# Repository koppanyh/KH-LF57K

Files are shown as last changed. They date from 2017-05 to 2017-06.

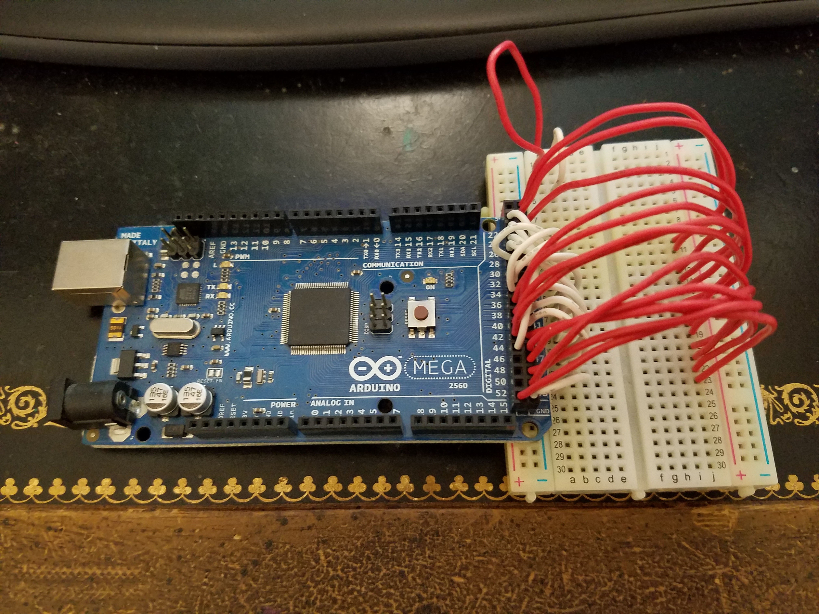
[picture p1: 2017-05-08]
hardware/programmer_real.jpg

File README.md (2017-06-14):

# KH-LF57K
Code and design files for a custom Z80 computer with Forth operating system.

The KH-LF75K computer is a Z80 based single-board computer that was designed, built, and programmed by Koppany Horvath as a project for the University of La Verne's 2nd Mini Makers fair. The first version (0.9.4) of the code was over 1300 lines of assembly and written in less than a week; no small feat when you consider that I never wrote a line of Z80 assembly before.

This is a collection of the software files for the operating system itself as well as any firmware for the Arduino microcontrollers used. Schematics and documentation of the hardware will also be stored here.

All of this content here is free to use for whatever you want. It is under the MIT License but I also require that you mention my name or GitHub account if you use any of my resources for anything.

Read the "/UsersManual.pdf" file for more information on the computer.

The "/arduino/eepromprog" folder has the sketch for an Arduino Mega 2560 based EEPROM programmer and the schematic to hook it up.
The "/arduino/z80controller" folder contains the sketch for the Arduino Nano based serial communication module used on the KH-LF57K computer.

The "/forth" folder contains the source code for the Forth operating system. This is a custom Forth implementation that is not ANSI compliant and works a little differently than most traditional Forth implementations.
The "/forth/forth.cpp" file is the C++ file that contains a Forth interpreter/compiler prototype that was used for porting the interpreter to Z80 assembly.
The "/forth/z80os.asm" file is the assembly file that contains the ported version of the Forth interpreter from the C++ file; it is specifically written for the KH-LF57K computer but should be easy to port to another Z80 based system by modifying the addresses and input/output subroutines; it also contains a 2 byte header that holds the size of the code to be uploaded to the Arduino for EEPROM programming.
The "/forth/buildscript.sh" file is a script that re-compiles the assembly file every time there is a change to it.

The "/hardware/computer_layout.{png,svg}" files are rought schematics of the laout of the actuall KH-LF57K board. The address (yellow) and data (green) lines aren't shown, but to complete the circuit, just connect all the data lines for all the chips to the right ones on the Z80, same for the address lines. The Arduino Nano uses pins D2-D9 as the data lines for D0-D7.
The "/hardware/computer_layout.fzz" file is the Fritzing file for the computer_layout files.
The "/hardware/eeprom_programmer_schem.{png,svg}" files are a rough schematic of how to hook up the Arduino Mega 2560 to the EEPROM chip.
Schematics use red for positive 5 volts, black for ground, white for signal lines, yellow for address lines, and green for data lines.
The capacitor on the computer is rated at 0.47 uf.

The "/computer_real.jpg" and "/programmer_real.jpg" files are pictures of the actual computer and the actual programmer circuit. You'll might notice a few differences, like the chips being wider or the power supply being different, but those small details won't affect the computer.

The "/z80os-0.9.4.bin" file is the compiled version of the "/forth/z80os.asm" file; the first 2 bytes are the size of the program, the rest is the program starting from address $0000.
This file was compiled with version 1.8 of the z80asm assembler program.

**To Do**
* look into potential bug that looks through whole memory for command
* write all built-in words in assembly for speed and finish words in assembly
* fix all comparisons to use the cp opcode instead of sbc
* add over/underflow errors to return and loop stacks
* fix the stack functions to use the hardware stack
* fix backspacing into other memory

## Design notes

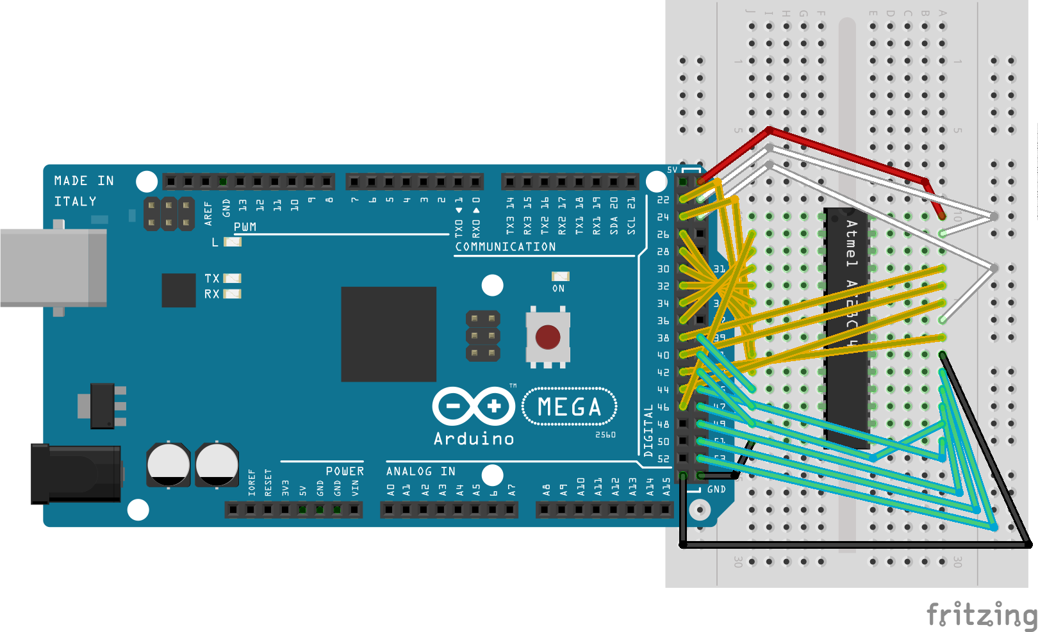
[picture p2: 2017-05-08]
hardware/eeprom_programmer_schem.png

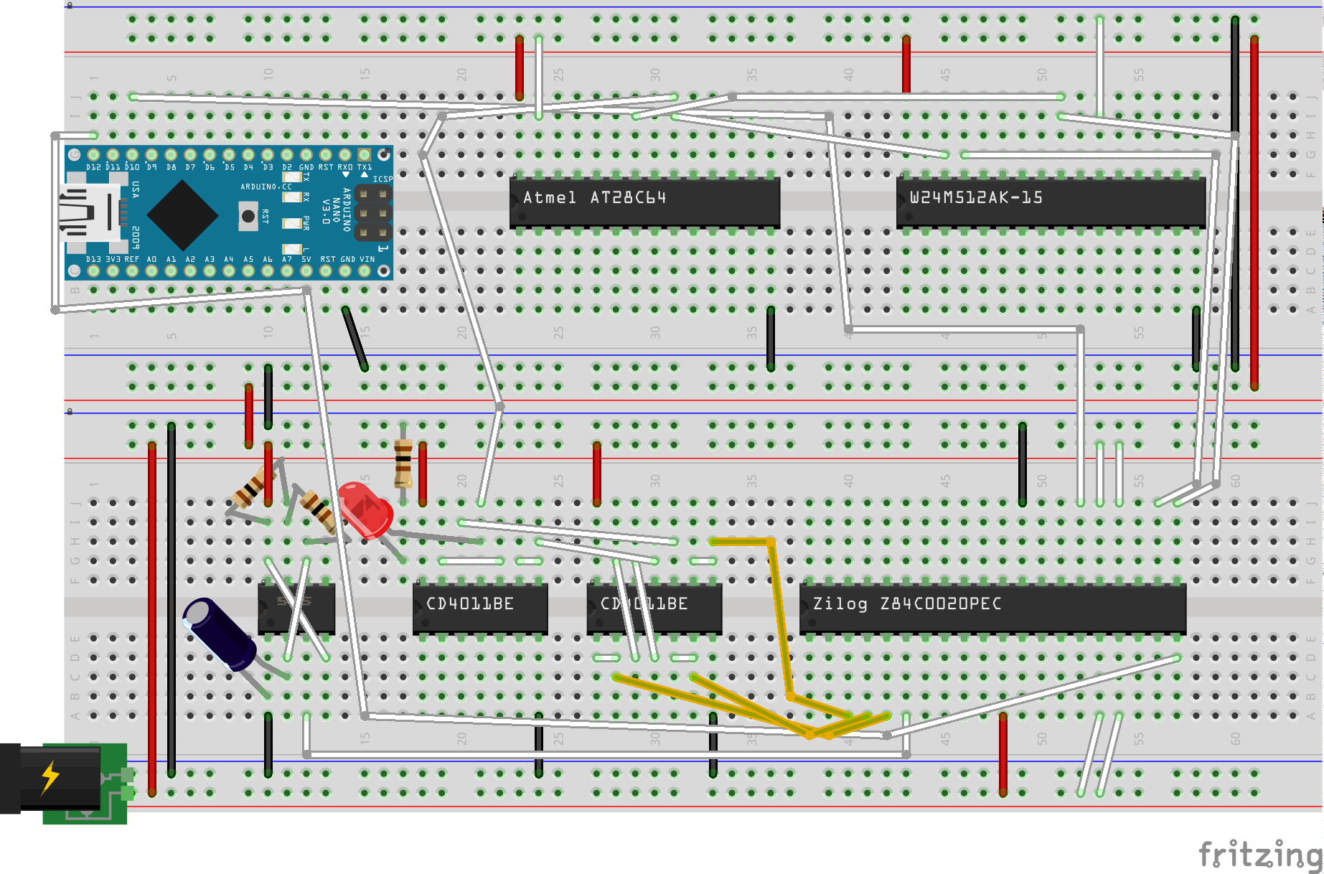
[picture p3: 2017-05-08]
hardware/computer_layout.png

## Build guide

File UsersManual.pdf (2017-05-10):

# KH-LF57K

© 2017 KH-Labs

Developer’s User Manual

“The best 1980s computer made from 1970s and 1990s technology!” -Koppany Horvath

Rev 1.0 - 2017 / 05 / 09

## Contents

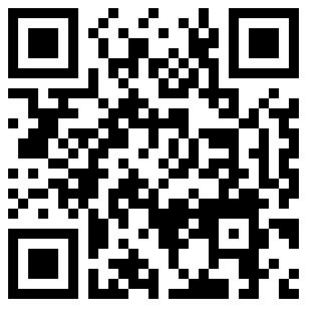
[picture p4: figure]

Additional Resources: https://github.com/koppanyh/KH-LF57K

Rev 1.0 1

## General Description

The KH-LF57K computer is a microcomputer designed by the KH-Labs development team with the goal of being built from the bare minimum parts required to run a Forth operating system on a Zilog Z80 processor with memory, a ROM, and serial communications capabilities. The name KH-LF57K stands for KH-Labs Forth OS 57 KB of RAM Microcomputer.
This computer was designed and built for the initial purpose of entering the University of La Verne’s second annual Mini Maker Fair. It took a week to write and debug the operating system. The Z80 assembly language was never used by the development team before. Future plans for the computer involve research into 1980s software development along with work on optimizing the Forth operating system. Work on upgrading the hardware and speeding up the computer is also planned. If possible, working on giving the computer the look and feel of an authentic 1980s computer, particularly with the style of CBM computers, will also be attempted.

## Hardware Specs

- 8 bit Zilog Z80 processor
- 10.34 KHz clock speed
- 57 KB of RAM
- 8 KB of ROM memory
- 115200 baud serial module
- CMOS memory switching logic

## Addressing/Serial

The addressing capabilities of the KH-L57K computer are split between the ROM, RAM, and serial module.
The ROM can be addressed between addresses 0x0000 and 0x1FFF.
The RAM can be addressed between 0x2000 and 0xFFFF.
The serial module can be addressed using the IO request line. The first IO request will have to be sending data to the serial module as the serial module will be in a listening mode, then the second IO request will receive data from the serial module as the serial module will be waiting to transmit. The serial module then switches to receiving mode and waits for another byte from the processor. The serial module is capable of asynchronously transmitting and receiving between the processor and a serial terminal at 115200 baud. The serial module can buffer at most 64 bytes of data from a serial terminal waiting to be read by the processor. The serial module does not buffer data from the processor but instantly transmits each byte to the serial terminal.

## Block Diagram

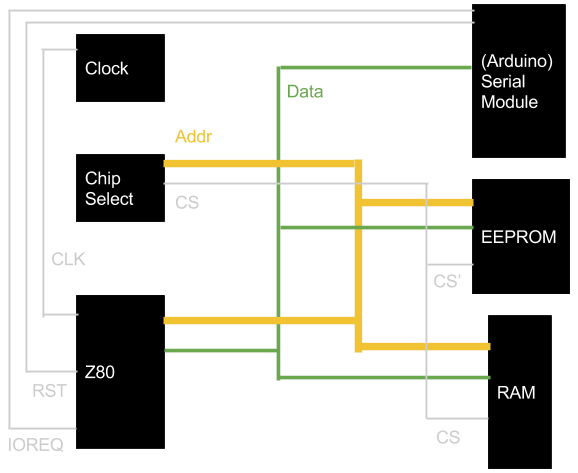
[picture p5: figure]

## Parts List

- 1x MB102 Breadboard Power Supply
- 1x Zilog Z84C0020PEC CMOS Z80 CPU
- 1x AT28C64-15PC 8KX8 EEPROM
- 1x W24M512AK-15 64KX8 SRAM
- 1x Arduino Nano Microcontroller
- 1x 0.47 µf Electrolytic Capacitor
- 2x CD4011 Quad NAND Gates
- 1x Red Difuse LED
- 1x LM555 Timer IC
- 3x 100 Ω Resistors

## Schematics

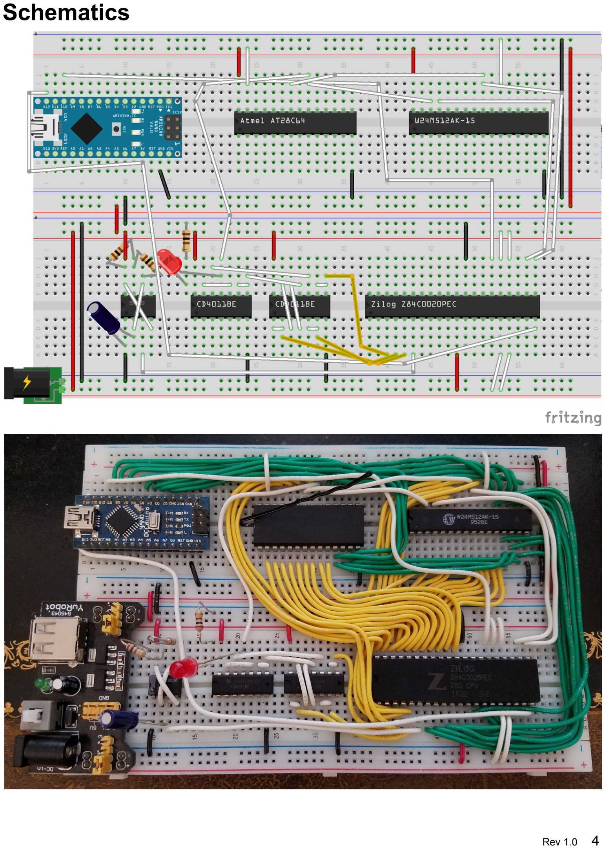
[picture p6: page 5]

The first figure is a rough representation of the layout of the computer without address or data lines. To complete the schematic, the data lines simply need to be connected to between the corresponding data pins on the processor, ROM, RAM, and serial module. The serial module uses pins D2-D9 as data pins 0-7 correspondingly. The address lines need to be connected between the address pins on the processor, ROM, RAM, just like the data lines. The serial module does not require address lines to operate.
The second figure shows a built KH-LF57K computer. The figure demonstrates the connections of the address (yellow) and data (green) lines between the processor (bottom right), RAM (top right), ROM (top middle), and serial module (top left).
In the first figure, there are 3 address lines going from the processor to the CMOS memory switching logic chips (bottom middle). These are 2 2-input quad NAND chips wired to work as a 3-input OR gate. Addressing the RAM will set the top 3 address bits high and trigger a high response on the OR gate which will select the RAM chip for reading and writing. Addressing the ROM under that will deactivate the OR gate and select the ROM chip.
A 555 timer chip is used to provide the clock signal at about 10.34 KHz. The 555 timer is configured as an astable oscillator. Unfortunately this particular clock circuit is not the most accurate and is subject to problems such as thermal drift and slightly different frequencies per unit due to the precisions and tolerances of the components being slightly different. The processor can run at 20 MHz but no more than 1 MHz is recommended as it may be too fast to interface with the serial module.

## Forth OS

The Forth language was chosen for the operating system of the KH-LF57K computer because of its ease of implementation and the small resources that are required to run it. The Forth language can generally fit in less space than BASIC, is natively extensible through the use of the built-in compilation capabilities, and has been around since 1970.
Forth is a stack-based language that uses reverse Polish notation (or post-order notation) and is also its own development environment. Words, functions in Forth, are created using the concept of concatenative programming. A more detailed explanation of the Forth language can be found on Wikipedia.com at the following address: https://en.wikipedia.org/wiki/Forth_(programming_language)
The Forth version in use at the time of this revision is 0.9.4; keep in mind that this is a custom implementation of Forth and the version number is not related to any other Forth implementations or standards.
An example of adding 5 and 4 and printing it out in Forth can be seen below:
5 4 + .
This code pushes 5 and 4 onto the top of the stack. Then it adds the top 2 items of the stack together with the plus operator. Then it prints out the result at the top of the stack with the period operator.

An example of defining a Forth word that prints the double of a number at the top of the stack can be seen below:
: double 2 * . ;
This code starts the compilation sequence with the colon operator and creates the header for the word double. It then defines the word based on the operators following the name. When called, this code will push 2 to the top of the stack. It then will multiply the 2 with the second number on the stack using the multiplication operator and will leave the result at the top of the stack. Then it will use the period operator to print out the result at the top of the stack.
The semicolon operator ends the compilation sequence and the word double | can be seen as
the first word when the words | word is called.
To use the new double | word, simply enter in a number and call double | as seem
below:
| 7 double
This code will push 7 to the top of the stack and then call the word double | to multiply
the number by 2 and print the result.
Here is a table of all the Forth words that have been implemented in version 0.9.4 of the Forth OS. For the flags, M means it is machine code, I means it is an immediate word, C means it it compiled. Lack of M means it is written in Forth, lack of I means it compiles normally, lack of C means that it can be used out of compilation.
Name | Flags | Stack Action | Description
LIT | MC | ( -- n1 ) | get next number from program and push to stack
, | M | ( n1 -- ) | writes n1 into the memory at WEND and updates WEND position
+ | M | ( n1 n2 -- n3 ) | add n2 to n1
- | M | ( n1 n2 -- n3 ) | subtract n2 from n1
* | M | ( n1 n2 -- n3 ) | multiply n2 to n1
/mod | M | ( n1 n2 -- n3 n4 ) | divide and mod n2 from n1
emit | M | ( n1 -- ) | output the character of the ascii value of n1
, | M | ( n1 -- ) | display n1 followed by a space
CREATE | M | ( n1 -- ) | create the header for a word/constant/variable from string address n1
c! | M | ( n1 n2 -- ) | save the low 8 bits of n1 to the address n2
c@ | M | ( n1 n2 -- ) | get the byte at the address n1
! | M | ( n1 n2 -- ) | save n1 to the address n2

@ | M | ( n1 -- n2 ) | get the value at the address n1
STATE | | ( -- n1 ) | leave the address of the state variable in the stack, 0 is interpret, -1 is compile
LATEST | | ( -- n1 ) | leave the address of the latest word variable in the stack
WEND | | ( -- n1 ) | leave the address of the end of words variable in the stack
BKEY | MC | ( -- n1 ) | gets next char from input buffer and leaves in stack
BWORD | MC | ( -- n1 ) | gets next word in input buffer and leaves address in stack
: | I | ( -- ) | start compiling sequence, create and state to -1
; | IC | ( -- ) | add 0xffff to the end of program and make state 0
key | M | ( -- n1 ) | get the ascii value of the first key pressed
word | M | ( -- n1 ) | gets a string from input and leaves the address of the string
number | M | ( -- n1 ) | gets a number from input
words | M | ( -- ) | display all the words in the forth dictionary
swap | M | ( n1 n2 -- n2 n1 ) | switch the top 2 elements on the stack
dup | M | ( n1 -- n1 n1 ) | duplicates top of stack
drop | M | ( n1 -- ) | pop n1 from stack
= | M | ( n1 n2 -- n3 ) | true if n1 equals n2, else false
<> | M | ( n1 n2 -- n3 ) | true if n1 not equals n2, else false
< | M | ( n1 n2 -- n3 ) | true if n1 less than n2, else false
> | M | ( n1 n2 -- n3 ) | true if n1 greater than n2, else false
<= | M | ( n1 n2 -- n3 ) | true if n1 less than equal n2, else false
>= | M | ( n1 n2 -- n3 ) | true if n1 greater than equal n2, else false
and | M | ( n1 n2 -- n3 ) | logic and n1 & n2
or | M | ( n1 n2 -- n3 ) | logic or n1 & n2

xor | M | ( n1 n2 -- n3 ) | logic xor n1 & n2orr
.s | M | ( -- ) | display all the numbers in the stack without popping the stack
reboot | M | ( -- ) | restarts the computer
>r | M | ( n1 -- ) | push n1 to the return stack
r> | M | ( -- n1 ) | pop n1 from the return stack
r@ | M | ( -- n1 ) | copy the top value from the return stack
>l | M | ( n1 -- ) | push n1 to the loop stack
l> | M | ( -- n1 ) | pop n1 from the loop stack
type | M | ( n1 -- ) | string is displayed starting from the address n1
FIND | M | ( -- n1 ) | find the address n1 of a word with name in wordbuff
WBUFF | | ( -- n1 ) | leaves the address of the start of the word buffer in the stack
EXEC | M | ( n1 -- ) | executes the word with address n1
BRANCH | MC | ( -- ) | replace the top of return stack with next number in program
0BRANCH | MC | ( -- ) | replace the top of return stack with next number in program if top of stack is 0
VERSION | | ( -- n1 ) | leave the forth version * 100 on the stack
constant | I | ( n1 -- ) | create a word that leaves the value n1 in the stack
variable | I | ( -- ) | create a word that leaves the address for a variable in the stack

## Useful Forth Words

As can be seen from the table above, there are many Forth words that have been defined and added into version 0.9.4 of the operating system, but not all of the most common words have been added. This was due to time constraints and accepting the trade-off of not having the words but having the capability to produce them on the spot.

The following code is the human definition (prefixed by a comma) of the words followed by their Forth definition.
; / | ( n1 n2 -- n3 ) divide n1 by n2, leave result n3
: / /mod drop ;
; mod | ( n1 n2 -- n3 ) get n1 modulus n2, leave result n3
: mod /mod swap drop ;

; negate ( n1 -- n2 ) leaves 2's complement of n1 in stack
: negate 0 swap - ;

; over ( n1 n2 -- n1 n2 n1 ) duplicates second number in stack : over >l dup l> swap ;

; rot | ( n1 n2 n3 -- n2 n3 n1 ) rotates third number to top
: rot >l swap l> swap ;

; -rot ( n1 n2 n3 -- n3 n1 n2 ) rotates top to third place
: -rot swap >l swap l> ;

; cells ( n1 -- n2 ) multiplies n1 with size of number cell (2) : cells 2 * ;

; cr | ( -- ) prints a carriage return and newline
: cr 13 emit 10 emit ;

; invert ( n1 -- n2 ) logic not n1
: invert -1 xor ;

; allot ( n1 -- ) increment program end counter by n1
: allot WEND @ + WEND ! ;

; IMMEDIATE ( -- ) activate immediate flag on latest word : IMMEDIATE 64 LATEST @ c@ or LATEST @ c! ; IMMEDIATE

; COMPILE ( -- ) activate compile flag on latest word
: COMPILE IMMEDIATE 32 LATEST @ c@ or LATEST @ c! ;

; INSADDR ( -- n1 ) insert address of following word in compiling word
: INSADDR IMMEDIATE BWORD drop FIND , ;

; begin ( -- ) specified return address for repeat/until
: begin IMMEDIATE WEND @ >l ;

; until ( n1 -- ) jump to begin statement in begin-until loop if n1 false
: until IMMEDIATE INSADDR LIT INSADDR 0BRANCH , l> , ;
; ( | ( -- ) start of comment, ends at first ) character
: ( IMMEDIATE begin BKEY 41 = until BKEY drop ;

## Flashing the ROM

The ROM chip can be flashed from an EEPROM programmer circuit built from an Arduino Mega microcontroller. The firmware for the EEPROM programmer can be found in the Code Listings section.
The Arduino will have to be wired up in a similar fashion to the figure below. The even numbered pins from 22 to 46 are connected to the address lines 0 to 12 respectively. The odd numbered pins from 39 to 53 are connected to the data lines 0 to 7 respectively. The Chip Enable pin of the EEPROM is connected to ground. The Write Enable pin is connected to pin
23. The Output Enable pin is connected to pin 25 of the Arduino. Voltage lines can be hooked up to the 5V and GND pins of the Arduino.
The EEPROM programmer firmware for the Arduino will allow the EEPROM chip to be programmed over a serial connection, thus avoiding having to reprogram the Arduino with a new ROM image every time the ROM needs to be updated.
The recommended software to handle the serial upload is CuteCom, website: http://cutecom.sourceforge.net/. The serial speed setting should be set to 115200 baud. The device or port is dependent on the system the Arduino is connected to. The data bits and stop bits should be set to 8 and 1 respectively. The char delay should be set to 10 ms to ensure that the Arduino has time to write a byte before receiving another one. The ROM image can be send over the Send File option. The output screen will show messaged from the Arduino stating that it is connected, showing the size of the program, and displaying the contents of the program along with a “Done” message when it has written the specified amount of bytes.
The ROM file itself has 2 bytes in the beginning as a header to hold the size of the program. The ROM will be written to the EEPROM starting from address 0 of the chip until the address that is minus one of the header size.
The ROM source code is found in the Code Listings section under the “Z80 assembly for the Forth OS” section. The source is written to be compiled by version 1.8 of the z80asm assembler found at this website: http://www.nongnu.org/z80asm/. When compiled, it will automatically add the 2 bytes size header with the size specified by the end of the “endOfProg” header near the bottom.

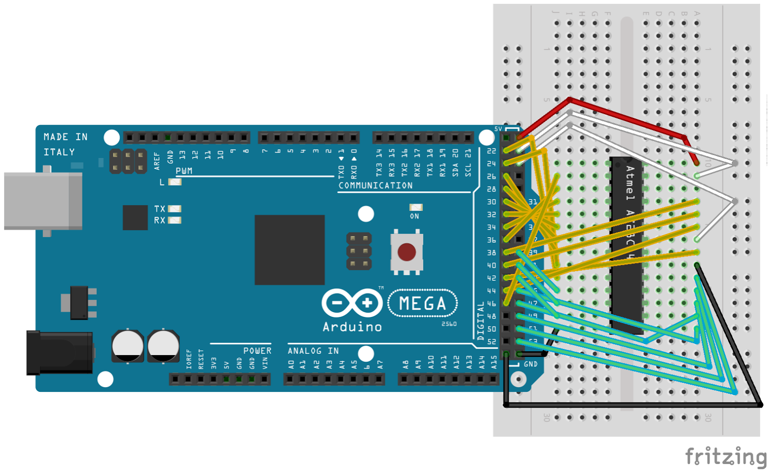
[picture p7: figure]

## Code Listings

Due to the length of the programs, the code will not be listed in this manual directly. The listings for the programs can be found at the following links.

The Z80 assembly for the Forth OS: https://github.com/koppanyh/KH-LF57K/blob/master/forth/z80os.asm

The C++ prototype program that the Forth OS was ported from: https://github.com/koppanyh/KH-LF57K/blob/master/forth/forth.cpp

The firmware for the Arduino Nano based serial/control module: https://github.com/koppanyh/KH-LF57K/blob/master/arduino/z80controller/z80controller.ino

The firmware for the Arduino Mega 2560 based EEPROM programmer: https://github.com/koppanyh/KH-LF57K/blob/master/arduino/eepromprog/eepromprog.ino

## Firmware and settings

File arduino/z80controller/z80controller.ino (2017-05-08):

const int outPin = 12;
const int clkPin = 11;
const int rstPin = 10;

bool ioreq = false;
bool reqstage = true;
char inp;
bool clockstage = true;

void setup(){
  pinMode(outPin, INPUT);
  //pinMode(clkPin, OUTPUT);
  pinMode(rstPin, OUTPUT);
  pinMode(13, OUTPUT);
  
  digitalWrite(rstPin, LOW); //reset processor

  Serial.begin(115200);
  for(int i=2; i<10; i++) pinMode(i, INPUT);
  
  //analogWrite(clkPin, 128); //start clock at around 500hz
  delay(100);
  digitalWrite(rstPin, HIGH);
}

void loop(){
  ioreq = !digitalRead(outPin);
  digitalWrite(13, ioreq); //show io req

  if(ioreq){
    if(reqstage){ //read data from bus
      inp = 0;
      for(int i=2; i<10; i++){
        inp >>= 1;
        if(digitalRead(i)) inp |= 0x80;
        else inp &= 0x7f;
      }
      if(inp != 0) Serial.print(inp);
      reqstage = false;
    } else{ //write data to bus
      if(Serial.available()) inp = Serial.read();
      else inp = 0;
      for(int i=2; i<10; i++){
        pinMode(i, OUTPUT);
        digitalWrite(i, inp & 0x01);
        inp >>= 1;
      }
      reqstage = true;
    }
    while(!digitalRead(outPin)); //wait for ioreq to stop
    for(int i=2; i<10; i++) pinMode(i, INPUT); //set bus pins to high impedance
  }
}

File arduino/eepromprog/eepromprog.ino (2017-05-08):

void setAdr(uint16_t addr){
  for(int i=0; i<13; i++){
    digitalWrite(22+i*2, addr & 0x0001);
    addr >>= 1;
  }
}
void datin(){
  for(int i=0; i<8; i++) pinMode(39+i*2, INPUT);
}
void datout(){
  for(int i=0; i<8; i++) pinMode(39+i*2, OUTPUT);
}

void writeByt(uint8_t byt, uint16_t addr){
  digitalWrite(25, HIGH); //OE' pin
  digitalWrite(23, HIGH);
  datout();
  setAdr(addr);
  for(int i=0; i<8; i++){
    if(byt & 0x0001) digitalWrite(39+i*2, HIGH);
    else digitalWrite(39+i*2, LOW);
    byt >>= 1;
  }
  digitalWrite(23, LOW);
  delayMicroseconds(500);
  digitalWrite(23, HIGH);
  delayMicroseconds(250);
}

uint8_t readByt(uint16_t addr){
  digitalWrite(23, HIGH); //WE' pin
  digitalWrite(25, HIGH);
  datin();
  setAdr(addr);
  uint8_t tmp = 0;
  digitalWrite(25, LOW);
  delayMicroseconds(250);
  for(int i=0; i<8; i++){
    tmp >>= 1;
    if(digitalRead(39+i*2)) tmp |= 0x80;
  }
  digitalWrite(25, HIGH);
  return tmp;
}

void setup(){
  Serial.begin(115200);
  pinMode(13, OUTPUT);
  for(int i=0; i<13; i++){ //address pins
    pinMode(22+i*2, OUTPUT);
    digitalWrite(22+i*2, LOW);
  }
  for(int i=0; i<8; i++){ //data pins
    pinMode(39+i*2, OUTPUT);
    digitalWrite(39+i*2, LOW);
  }
  pinMode(23, OUTPUT); //WE' pin
  digitalWrite(23, HIGH);
  pinMode(25, OUTPUT); //OE' pin
  digitalWrite(25, HIGH);

  while(!Serial.available()); //wait for serial
  Serial.println("Serial Link Established...");
  uint16_t plen = 0;
  while(!Serial.available());
  plen |= Serial.read() & 0xff;
  while(!Serial.available());
  plen |= (Serial.read() & 0xff) << 8;
  Serial.print("Size Of Program: ");
  Serial.print(plen);
  Serial.println(" bytes");
  
  delay(100);
  digitalWrite(13, HIGH);
  uint8_t bty, byt2;
  for(int i=0; i<plen; i++){
    while(!Serial.available());
    bty = Serial.read();
    writeByt(bty,i);
    byt2 = readByt(i);
    for(int j=0; j<100; j++){
      if(bty == byt2) break;
      if(j >= 99){
        Serial.println("\nWrite Error In Byte ");
        Serial.print((uint16_t)i, HEX);
        Serial.println("\n");
      }
      writeByt(bty,i);
      byt2 = readByt(i);
    }
    Serial.print((int)byt2, HEX);
    Serial.print(" ");
  }
  Serial.println(" ");
  Serial.println("Done...");
  digitalWrite(13, LOW);
}

void loop(){}

/*
 * 13 address pins
 * 8 data io pins
 * WE' write enable
 * OE' output enable
 */

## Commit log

2017-05-08 Updated forth.cpp to be more accurate.
    The latest forth.cpp file is more accurate to the assembly implementation and is the one that was most recently modified.
2017-05-08 Added pictures and schematics for the computer.
    [computer_layout.fzz]
2017-05-08 Moved schematics into hardware folder.
    [computer_layout.fzz]
